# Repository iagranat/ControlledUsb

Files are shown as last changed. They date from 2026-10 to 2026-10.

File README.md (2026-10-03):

# Controlled USB 2.0 Extension Cable

An intelligent USB 2.0 High-Speed (480 Mbps) inline extension cable with host-controlled power & data disconnection.

---

## 🛠️ System Architecture

```
                  +-------------------------------------------------------------+
                  |                     USB DONGLE                              |
                  |                                                             |
USB-A Male ------>| ===> CH334F 2-Port USB Hub                                  |
(From PC)         |       |                                                     |
                  |       +-- Port 1 ----> Waveshare RP2040-Zero (USB CDC Serial|
                  |       |                (GP16 = Onboard WS2812 RGB LED)      |
                  |       |                         |                           |
                  |       |             GP14 (PWR)  | GP15 (DATA)               |
                  |       |             Active HIGH | Active LOW                |
                  |       |                         v                           |
                  |       +-- Port 2 --+-> [CH440G High-Speed Switch] (D+/D-) ->|---> USB-A Female
                  |                    |                                        |     (Target Device)
                  |                    +-> [TPS22918 Load Switch] (VBUS, 2A) -->|
                  |                                                             |
                  |   GND (Common ground throughout) -------------------------->|
                  +-------------------------------------------------------------+
```

---

## 📌 Pinout & Connections

### RP2040-Zero
| RP2040 Pin | Connected To | Description / Logic |
| :--- | :--- | :--- |
| **GP16** | *Onboard WS2812* | Status RGB LED (Green = ON, Red = OFF, Yellow = Cycling, Blue = Charge) |
| **GP14** | **TPS22918** `ON` | High-side power switch enable (Active **HIGH**: `1` = 5V ON, `0` = 0V OFF) |
| **GP15** | **CH440G** `EN` | USB data switch output enable (Active **LOW**: `0` = Pass, `1` = Cut) |
| **GP26** | **Push Button** | Tactile button to GND (Internal pull-up enabled) |

---

## 🚦 RGB Status Indications

| Color | State | $V_{BUS}$ (Power) | $D+/D-$ (Data) | Description |
| :--- | :---: | :---: | :---: | :--- |
| 🟢 **Green** | `CONNECTED` | **ON** | **ON** | Normal operation. |
| 🔴 **Red** | `DISCONNECTED`| **OFF** | **OFF** | Completely unpowered and un-enumerated. |
| 🔵 **Blue** | `CHARGE_ONLY` | **ON** | **OFF** | Safe charging without data communication. |
| 🟡 **Yellow** *(Blinking)* | `CYCLING` | *Rebooting* | *Rebooting* | Active reboot/cycle in progress. |

---

## 🕹️ Controls

### 1. Serial Commands (115200 baud, Newline)
* `ON` or `CONNECT` — Connect power and data (with safe sequencing).
* `OFF` or `DISCONNECT` — Disconnect data first, then cut power.
* `CHARGE` — Keep 5V active, cut data lines.
* `CYCLE <ms>` — Reboot port for specified milliseconds (e.g. `CYCLE 1500`).
* `STATUS` or `?` — Query current state.
* `HELP` — List commands.

### 2. Physical Button
* **Short Click (< 1.2s)**: Toggle between `CONNECTED` and `DISCONNECTED`.
* **Long Press (> 1.2s)**: Trigger automated 1-second power cycle (`CYCLE 1000`).

---

## 🚀 Building & Flashing with PlatformIO

1. Plug the **RP2040-Zero** into your PC while holding the **`BOOT`** button.
2. Open this folder in Antigravity IDE (with the PlatformIO extension installed).
3. Click the **Build** (`✓`) button in the bottom status bar.
4. Click the **Upload** (`→`) button to flash the firmware.
5. Click the **Serial Monitor** (`🔌`) button to open the terminal.

---

## 🐍 Python CLI Utility

Run from the `tools/` folder:
```powershell
python switch_cli.py on
python switch_cli.py off
python switch_cli.py cycle 1000
python switch_cli.py status
```

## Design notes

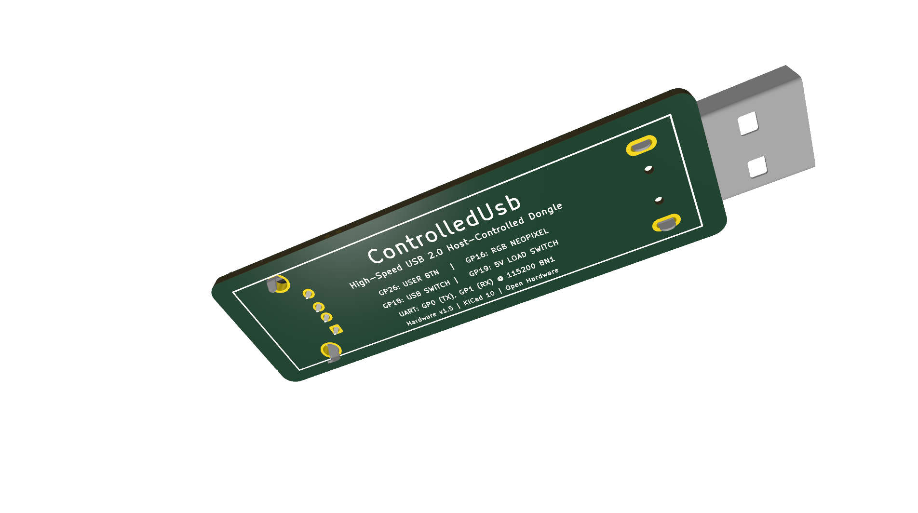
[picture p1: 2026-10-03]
hardware/ControlledUsb_3D_back.png

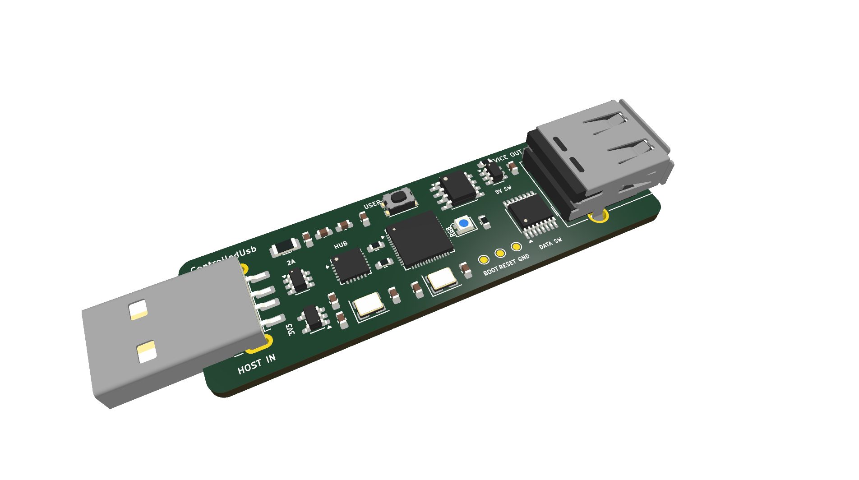
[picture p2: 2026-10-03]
hardware/ControlledUsb_3D_render.png

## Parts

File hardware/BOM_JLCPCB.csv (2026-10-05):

Comment | Designator | Footprint | LCSC Part #
RP2040 (Dual-Core Cortex-M0+ MCU) | U1 | Package_DFN_QFN:QFN-56-1EP_7x7mm_P0.4mm_EP3.2x3.2mm | C2040
PY25Q32HB-SSH-IR (4MB SPI Flash SOP-8) | U2 | Package_SO:SOIC-8_3.9x4.9mm_P1.27mm | C22439001
CH334F (USB 2.0 High-Speed 4-Port Hub QFN-24) | U3 | Package_DFN_QFN:QFN-24-1EP_4x4mm_P0.5mm_EP2.6x2.6mm | C5187527
TPS22918DBVR (5V 2A Load Switch SOT-23-6) | U4 | Package_TO_SOT_SMD:SOT-23-6 | C131941
CH440R (High-Speed USB Switch TSSOP-16) | U5 | Package_SO:TSSOP-16_4.4x5mm_P0.65mm | C282323
ME6211C33M5G-N (3.3V 500mA LDO SOT-23-5) | U6 | Package_TO_SOT_SMD:SOT-23-5 | C82942
USBLC6-2SC6 (USB ESD Protection SOT-23-6) | U7 | Package_TO_SOT_SMD:SOT-23-6 | C7519
12.000MHz SMD Crystal 3225-4P | Y1, Y2 | Crystal:Crystal_SMD_3225-4Pin_3.2x2.5mm | C9002
nSMD200 (PTC Resettable Fuse 2A 1206) | F1 | Fuse:Fuse_1206_3216Metric | C70085
USB-A Female Receptacle RA TH | J2 | Connector_USB:USB_A_Molex_67643_Horizontal | C2344
27R 1% 0603 | R1, R2 | Resistor_SMD:R_0603_1608Metric | C25114
10k 1% 0603 | R5, R6 | Resistor_SMD:R_0603_1608Metric | C25804
15pF 50V C0G 0603 | C1, C2 | Capacitor_SMD:C_0603_1608Metric | C1644
100nF 50V X7R 0603 | C3, C4, C5 | Capacitor_SMD:C_0603_1608Metric | C14663
1uF 50V X7R 0603 | C11 | Capacitor_SMD:C_0603_1608Metric | C15849
10uF 16V X5R 0603 | C13, C14, C15, C17 | Capacitor_SMD:C_0603_1608Metric | C19702

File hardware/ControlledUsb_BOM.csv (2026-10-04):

Refs | Value | Footprint | Qty | DNP
C1,C2 | 15pF | Capacitor_SMD:C_0603_1608Metric | 2
C3-C5 | 100nF | Capacitor_SMD:C_0603_1608Metric | 3
C11 | 1uF | Capacitor_SMD:C_0603_1608Metric | 1
C13-C15,C17 | 10uF | Capacitor_SMD:C_0603_1608Metric | 4
D1 | WS2812B | LED_SMD:LED_WS2812B-2020_PLCC4_2.0x2.0mm | 1
F1 | PTC 2A | Fuse:Fuse_1206_3216Metric | 1
J1 | USB_A_Male | Connector_USB:USB_A_CNCTech_1001-011-01101_Horizontal | 1
J2 | USB_A_Female | Connector_USB:USB_A_Molex_67643_Horizontal | 1
R1,R2 | 27R | Resistor_SMD:R_0603_1608Metric | 2
R5,R6 | 10k | Resistor_SMD:R_0603_1608Metric | 2
SW1 | USER_BTN | Button_Switch_SMD:SW_Push_1P1T_NO_CK_KMR2 | 1
TP1 | BOOT | TestPoint:TestPoint_Pad_D1.0mm | 1
TP2 | RESET | TestPoint:TestPoint_Pad_D1.0mm | 1
TP3 | GND | TestPoint:TestPoint_Pad_D1.0mm | 1
U1 | RP2040 | Package_DFN_QFN:QFN-56-1EP_7x7mm_P0.4mm_EP3.2x3.2mm | 1
U2 | W25Q32 | Package_SO:SOIC-8_3.9x4.9mm_P1.27mm | 1
U3 | CH334F | Package_DFN_QFN:QFN-24-1EP_4x4mm_P0.5mm_EP2.6x2.6mm | 1
U4 | TPS22918 | Package_TO_SOT_SMD:SOT-23-6 | 1
U5 | CH440P | Package_SO:TSSOP-16_4.4x5mm_P0.65mm | 1
U6 | ME6211C33 | Package_TO_SOT_SMD:SOT-23-5 | 1
U7 | USBLC6-2SC6 | Package_TO_SOT_SMD:SOT-23-6 | 1
Y1,Y2 | 12.000MHz | Crystal:Crystal_SMD_3225-4Pin_3.2x2.5mm | 2

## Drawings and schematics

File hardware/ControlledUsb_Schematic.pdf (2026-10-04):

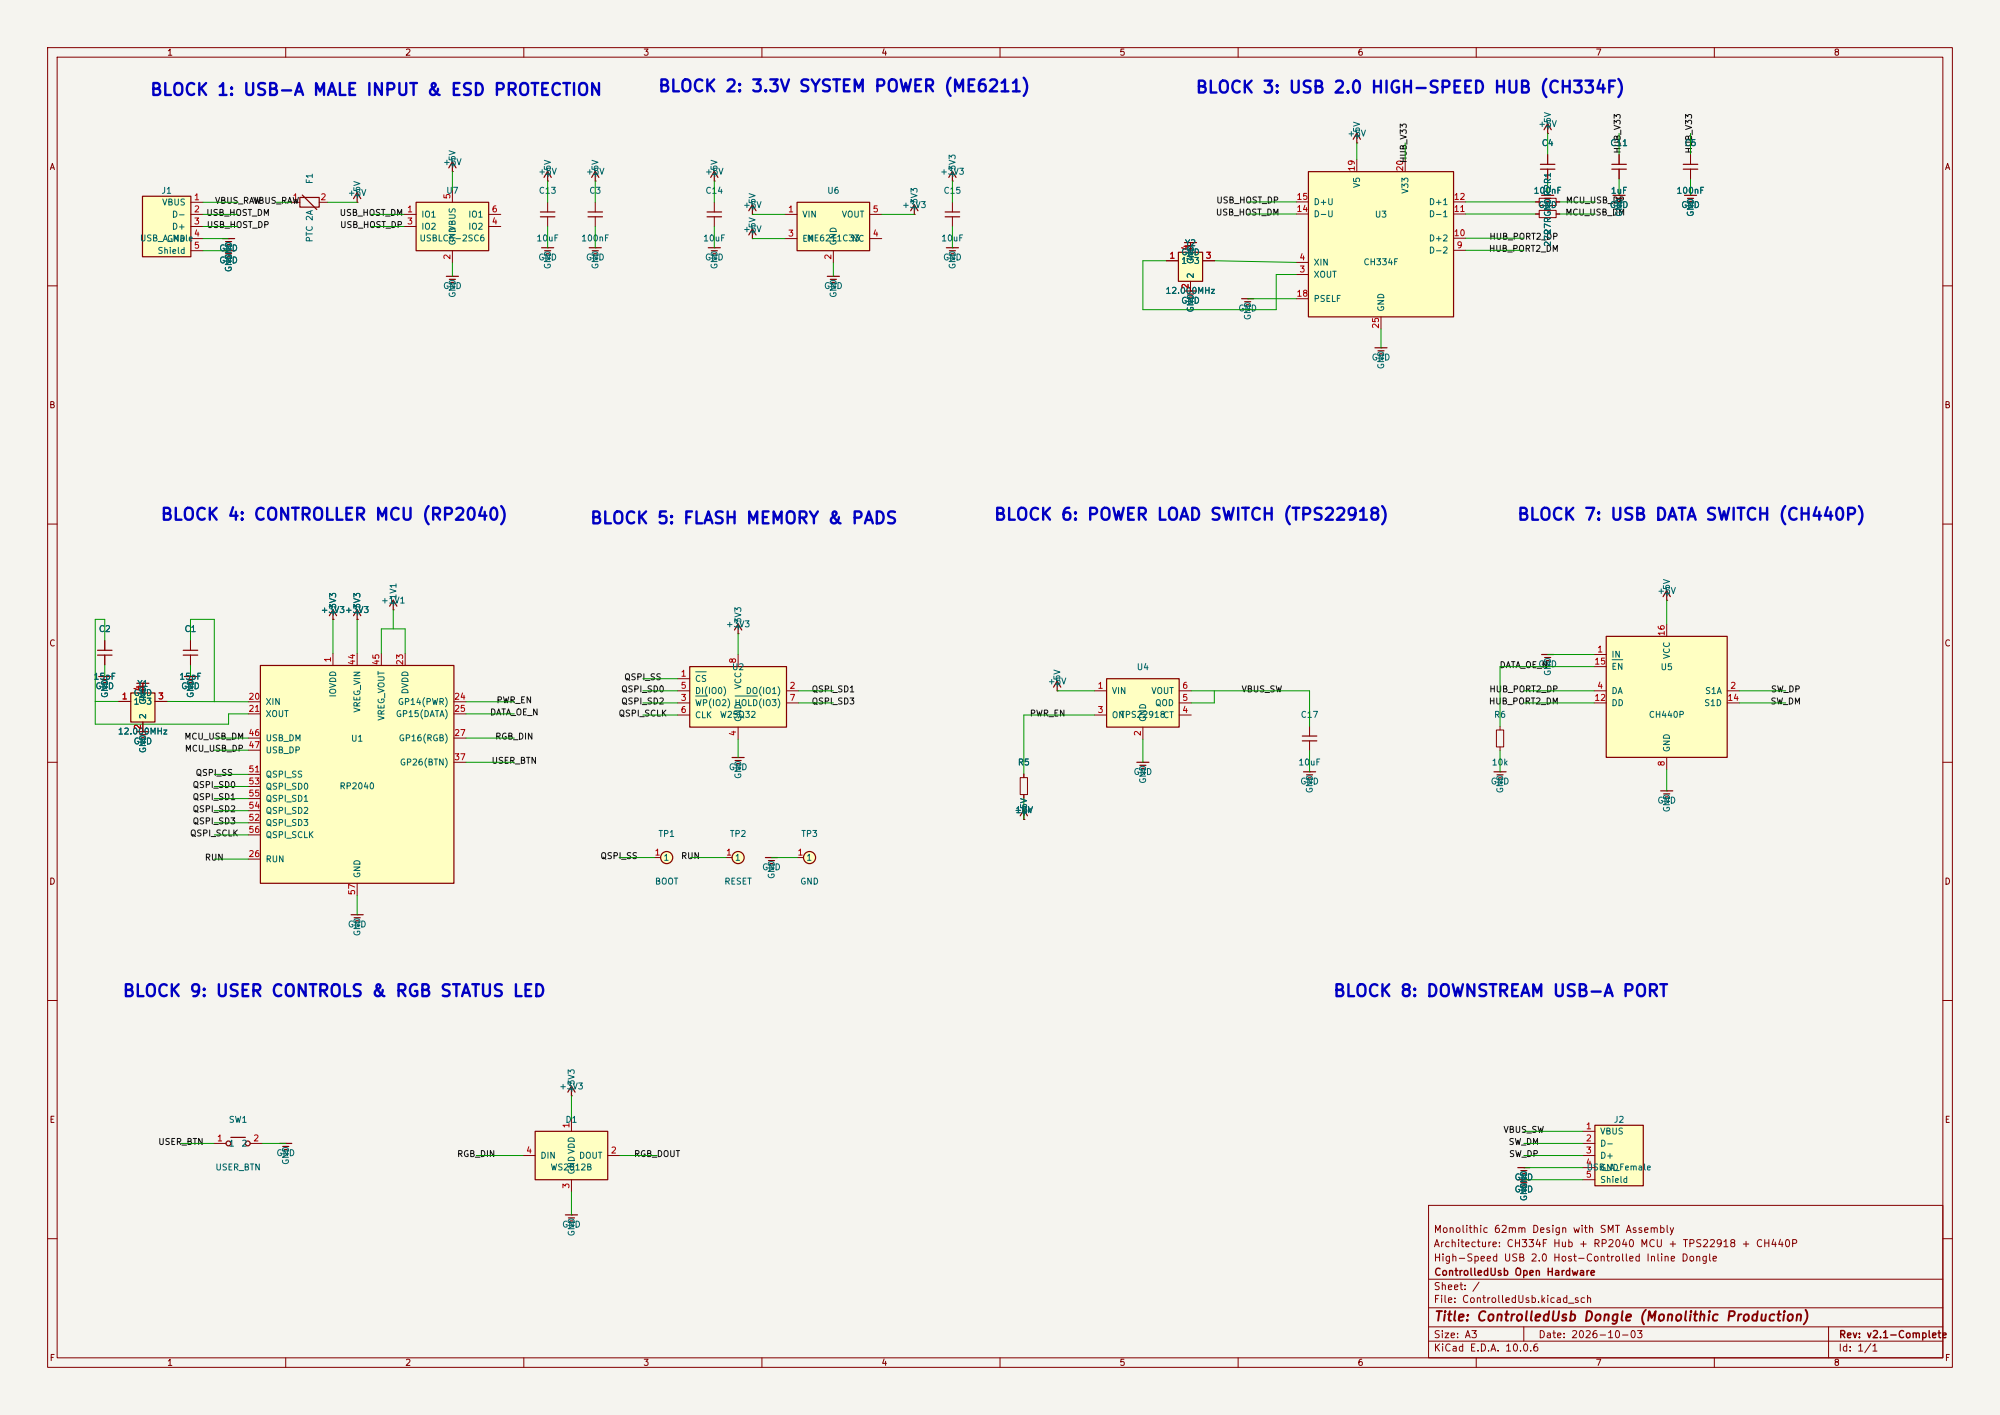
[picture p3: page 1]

BLOCK 1: USB-A MALE INPUT & ESD PROTECTION

BLOCK 3: USB 2.0 HIGH-SPEED HUB (CH334F)

USB_HOST_DM BLOCK 9: USER CONTROLS & RGB STATUS LED

Monolithic 62mm Design with SMT Assembly GND

8 U2 W25Q32 GND GND GND GND

BLOCK 5: FLASH MEMORY & PADS

BLOCK 7: USB DATA SWITCH (CH440P)

4 DI(IO0) 5 CLK 6 HOLD(IO3) 7 VCC

BLOCK 8: DOWNSTREAM USB-A PORT

Architecture: CH334F Hub + RP2040 MCU + TPS22918 + CH440P
High-Speed USB 2.0 Host-Controlled Inline Dongle
ControlledUsb Open Hardware
Sheet: /
File: ControlledUsb.kicad_sch
Title: ControlledUsb Dongle (Monolithic Production)

F Date: 2026-10-03

KiCad E.D.A. 10.0.6 | Id: 1/1

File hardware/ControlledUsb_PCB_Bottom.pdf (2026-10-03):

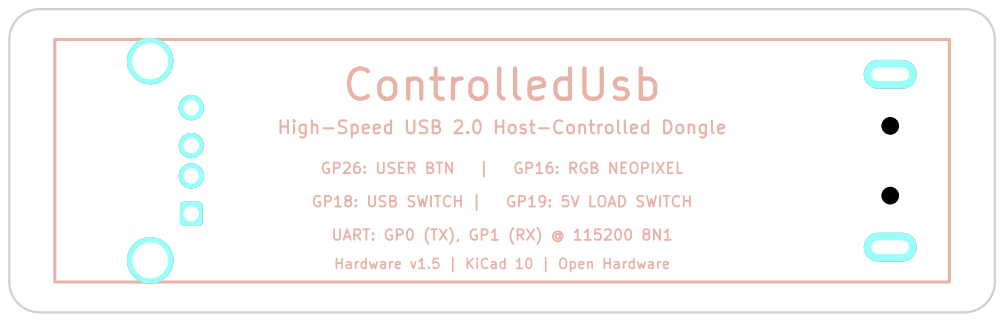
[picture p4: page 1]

UART: GP0 (TX), GP1 (RX) @ 115200 8N1 High-Speed USB 2.0 Host-Controlled Dongle ControlledUsb

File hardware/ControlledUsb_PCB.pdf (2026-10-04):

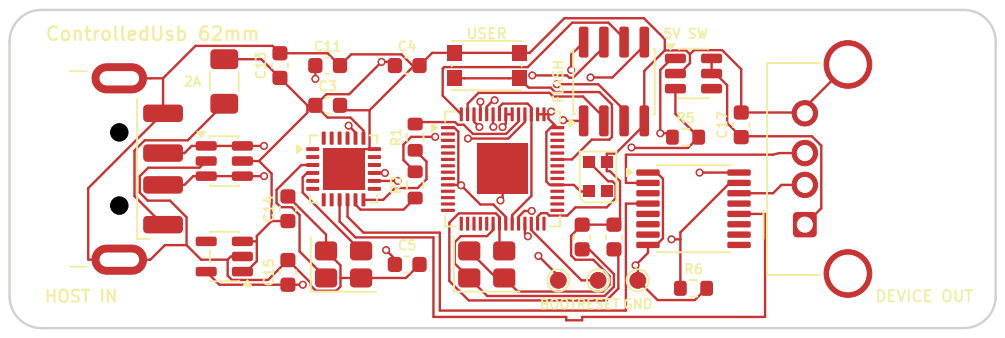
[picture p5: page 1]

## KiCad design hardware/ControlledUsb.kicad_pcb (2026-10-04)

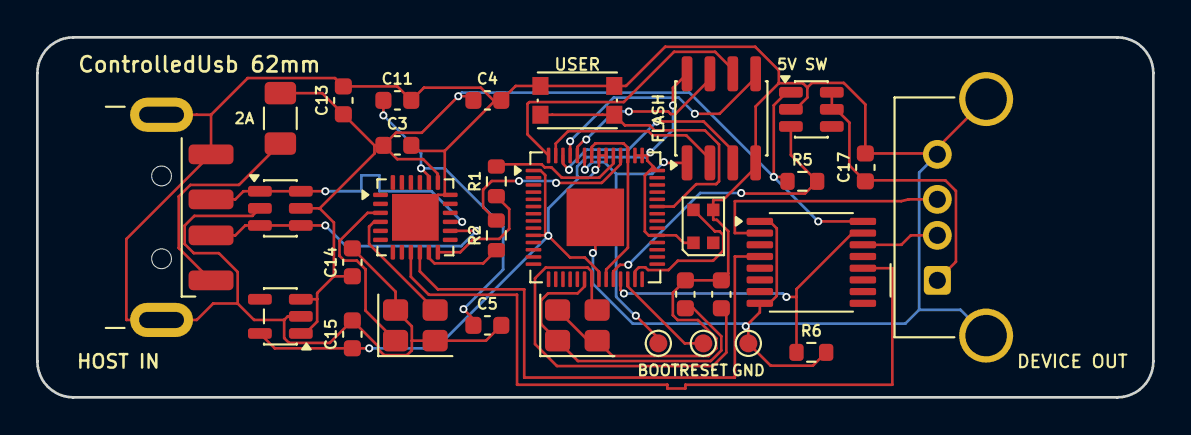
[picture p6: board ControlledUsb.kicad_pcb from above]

Board: 4 copper layers, 62.0 x 20.0 mm, 31 parts (0 on the bottom side), 32 nets.

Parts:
C1, C2: 15pF; C_0603_1608Metric
C3, C4, C5: 100nF; C_0603_1608Metric
C11: 1uF; C_0603_1608Metric
C13, C14, C15, C17: 10uF; C_0603_1608Metric
D1: WS2812B; LED_WS2812B-2020_PLCC4_2.0x2.0mm
F1: PTC 2A; Fuse_1206_3216Metric
J1: USB_A_Male; USB_A_CNCTech_1001-011-01101_Horizontal
J2: USB_A_Female; USB_A_Molex_67643_Horizontal
R1, R2: 27R; R_0603_1608Metric
R5, R6: 10k; R_0603_1608Metric
SW1: USER_BTN; SW_Push_1P1T_NO_CK_KMR2
TP1: BOOT; TestPoint_Pad_D1.0mm
TP2: RESET; TestPoint_Pad_D1.0mm
TP3: GND; TestPoint_Pad_D1.0mm
U1: RP2040; QFN-56-1EP_7x7mm_P0.4mm_EP3.2x3.2mm
U2: W25Q32; SOIC-8_3.9x4.9mm_P1.27mm
U3: CH334F; QFN-24-1EP_4x4mm_P0.5mm_EP2.6x2.6mm
U4: TPS22918; SOT-23-6
U5: CH440P; TSSOP-16_4.4x5mm_P0.65mm
U6: ME6211C33; SOT-23-5
U7: USBLC6-2SC6; SOT-23-6
Y1, Y2: 12.000MHz; Crystal_SMD_3225-4Pin_3.2x2.5mm

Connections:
+1V1: U1.23, U1.45, U1.50
+3V3: C15.1, D1.1, U1.1, U1.10, U1.22, U1.33, U1.42, U1.43, U1.44, U1.48, U1.49, U2.8, U6.5
+5V: F1.1, J1.1
+5V_FUSED: C3.1, C4.1, C13.1, C14.1, F1.2, R5.1, U3.19, U4.1, U5.16, U6.1, U6.3, U7.5
DATA_OE_N: R6.1, U1.25, U5.15
GND: C1.2, C2.2, C3.2, C4.2, C5.2, C11.2, C13.2, C14.2, C15.2, C17.2, D1.3, J1.4, J1.SH, J2.4, J2.SH, R6.2, SW1.1, TP3.1, U1.57, U2.4, U3.18, U3.25, U4.2, U5.1, U5.8, U6.2, U7.2, Y1.2, Y1.4, Y2.2, Y2.4
HUB_PORT1_DM: R2.1, U3.11
HUB_PORT1_DP: R1.1, U3.12
HUB_PORT2_DM: U3.9, U5.12
HUB_PORT2_DP: U3.10, U5.4
HUB_V33: C5.1, C11.1, U3.20
HUB_XI: U3.3, Y2.1
HUB_XO: U3.4, Y2.3
MCU_USB_DM: R2.2, U1.46
MCU_USB_DP: R1.2, U1.47
MCU_XI: C1.1, U1.20, Y1.1
MCU_XO: C2.1, U1.21, Y1.3
PWR_EN: R5.2, U1.24, U4.3
QSPI_SCLK: U1.56, U2.6
QSPI_SD0: U1.53, U2.5
QSPI_SD1: U1.55, U2.2
QSPI_SD2: U1.54, U2.3
QSPI_SD3: U1.52, U2.7
QSPI_SS: TP1.1, U1.51, U2.1
RGB_DIN: D1.4, U1.27
RUN: TP2.1, U1.26
SW_DM: J2.2, U5.14
SW_DP: J2.3, U5.2
USB_HOST_DM: J1.2, U3.14, U7.3, U7.4
USB_HOST_DP: J1.3, U3.15, U7.1, U7.6
USER_BTN: SW1.2, U1.37
VBUS_SW: C17.1, J2.1, U4.5, U4.6

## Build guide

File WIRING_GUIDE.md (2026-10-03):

# 🔌 Breadboard Wiring & Assembly Guide (Verified Working)

This guide details the exact, lab-verified breadboard wiring connections for **USBiagra** / **The Ilan-terrupter**.

---

## 📦 Components Overview

1. **CH334F 2-Port USB 2.0 Hub Breakout**
   * Upstream USB-C connects to PC Host.
   * `PORT1` (Top): Connects to RP2040-Zero (USB CDC Serial Controller).
   * `PORT2` (Bottom): Connects to Switched Downstream Port via TPS22918 & CH440G.
2. **Waveshare RP2040-Zero**
   * Firmware running Arduino/PlatformIO with USB CDC CLI, debounced button state machine, and NeoPixel status.
3. **CH440G USB 2.0 High-Speed Switch (SOP-16 Adapter)**
   * Switches differential data pair ($D+$ on Channel A, $D-$ on Channel D).
4. **TPS22918 Power Load Switch (SOT-23-6 DBV Adapter)**
   * Switches 5V $V_{BUS}$ up to 2A with Quick Output Discharge (QOD).
5. **USB-A Female Breakout**
   * Target downstream port.
6. **Push Button**
   * Connected between `GP26` and `GND`.

---

## 🗺️ Pin-to-Pin Connection Table

### 1. Power & Ground Rails
* **Hub `5V`** $\rightarrow$ **Breadboard Red (+) Rail**
* **Hub `GND`** $\rightarrow$ **Breadboard Blue (-) Rail**
* **All Grounds** (Hub, RP2040-Zero, CH440G Pin 8, TPS22918 Pin 2, USB-A Female GND) must tie to this common ground rail.

---

### 2. Hub Port 1 $\rightarrow$ RP2040-Zero (USB Serial CLI Control)
Using a 4-wire USB-C cable (plugged into RP2040-Zero USB-C receptacle) or direct wire:
* 🔴 **Red (5V)** $\rightarrow$ Hub Port 1 `5V` (or Breadboard 5V rail)
* ⚫ **Black (GND)** $\rightarrow$ Hub Port 1 `GND` (or Breadboard GND rail)
* 🟢 **Green (D+)** $\rightarrow$ Hub Port 1 `D+`
* ⚪ **White (D-)** $\rightarrow$ Hub Port 1 `D-`

---

### 3. CH440G Data Switch (SOP-16 Adapter) — *Verified Channels*
The CH440G switches the USB $D+/D-$ differential pair using Channel A and Channel D:

| CH440G Pin | Function | Connect To | Notes |
| :---: | :--- | :--- | :--- |
| **Pin 1** | `IN` | **GND Rail** | Selects Channel S1 (Low = S1 active) |
| **Pin 2** | `S1A` ($D+$ out) | **USB-A Female `D+`** | Switched $D+$ output to downstream port |
| **Pin 4** | `DA` ($D+$ in) | **Hub Port 2 `D+`** | High-speed $D+$ input from Hub |
| **Pin 8** | `GND` | **GND Rail** | System ground |
| **Pin 12** | `DD` ($D-$ in) | **Hub Port 2 `D-`** | High-speed $D-$ input from Hub |
| **Pin 14** | `S1D` ($D-$ out) | **USB-A Female `D-`** | Switched $D-$ output to downstream port |
| **Pin 15** | `EN#` | **RP2040 `GP15`** | Active LOW enable (0 = Pass, 1 = Tri-state). Add 10k pull-down to GND. |
| **Pin 16** | `VCC` | **5V Rail** | Chip power (place 0.1µF ceramic cap between Pin 16 and GND) |

*(Pins 3, 5, 6, 7, 9, 10, 11, 13 are unused/isolated).*

---

### 4. TPS22918 Power Switch (SOT-23-6 DBV Adapter) — *Verified Pinout*
Controls 5V $V_{BUS}$ power line up to 2A with active discharge:

| TPS22918 Pin | Function | Connect To | Notes |
| :---: | :--- | :--- | :--- |
| **Pin 1** | `VIN` | **Breadboard 5V Rail** | 5V Input from Hub. Add 1µF–10µF bulk capacitor to GND. |
| **Pin 2** | `GND` | **GND Rail** | System ground |
| **Pin 3** | `ON` | **RP2040 `GP14`** | Active HIGH enable (1 = 5V ON, 0 = 0V OFF). Add 10k pull-up to 5V. |
| **Pin 4** | `CT` | *Leave Floating* | Slew rate capacitor (internal fast ~100µs ramp) |
| **Pin 5** | `QOD` | **Tie to Pin 6 (`VOUT`)** | Quick Output Discharge (bleeds downstream rail to 0V when OFF) |
| **Pin 6** | `VOUT` | **USB-A Female `VBUS`** | Switched 5V output to downstream port |

---

### 5. Downstream Extension Port (USB-A Female Breakout)
* **`VBUS`** $\rightarrow$ From TPS22918 **Pin 6 (`VOUT`)**
* **`D-`** $\rightarrow$ From CH440G **Pin 14 (`S1D`)**
* **`D+`** $\rightarrow$ From CH440G **Pin 2 (`S1A`)**
* **`GND`** $\rightarrow$ Common **GND Rail**

---

### 6. Physical Controls & RP2040 Pin Assignment
* **`GP14`** $\rightarrow$ TPS22918 Pin 3 (`ON`)
* **`GP15`** $\rightarrow$ CH440G Pin 15 (`EN#`)
* **`GP26`** $\rightarrow$ Push button (other terminal to `GND`)
* **`GP16`** $\rightarrow$ Onboard WS2812 RGB LED:
  * 🟢 **Solid Green**: Connected (Power ON, Data ON)
  * 🔴 **Solid Red**: Disconnected (Power OFF, Data OFF)
  * 🔵 **Solid Blue**: Charge Only (Power ON, Data OFF)
  * 🟡 **Blinking Yellow**: Power Cycling (Auto reboot)

---

## ⚡ High-Speed (480 Mbps) Wiring Guidelines

When testing high-speed devices (flash drives, SSDs, webcams) on breadboard:
1. **Short Length**: Keep $D+$ and $D-$ wire runs as short as possible (~3 to 5 cm max).
2. **Length Match**: Cut the $D+$ and $D-$ wires to the identical length (within 2-3 mm).
3. **Twisted Pairs**: Lightly twist the Hub $D+/D-$ pair together, and the USB-A Female $D+/D-$ pair together to preserve 90Ω differential impedance.
4. **Direct Ground Return**: Ensure the USB-A Female GND wire runs directly to the common ground rail adjacent to the signal wires.

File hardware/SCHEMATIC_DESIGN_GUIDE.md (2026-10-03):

# 📐 ControlledUsb Hardware Design & Schematic Guide

**Version**: 1.0 (Monolithic Production Architecture)  
**Form Factor**: Slim USB Dongle (approx. 19 mm × 54 mm)  
**Target Fabrication**: JLCPCB 4-Layer PCB with SMT Assembly (Target total order < $55 USD)

---

## 1. System Architecture Overview

```mermaid
flowchart LR
    Host["Host PC<br/>(USB-A Male)"] --> FUSE["PTC 2A Fuse<br/>& USBLC6 ESD"]
    FUSE --> VBUS_BUS["+5V Main Rail"]
    FUSE --> HUB["WCH CH334F<br/>USB 2.0 Hub (QFN-24)"]
    
    VBUS_BUS --> LDO["ME6211<br/>3.3V LDO"]
    LDO --> RP["RP2040 MCU<br/>& W25Q32 Flash"]
    
    HUB -- "Port 1 (Full-Speed)" --> RP
    
    RP -- "GP14 (PWR_EN)" --> TPS["TI TPS22918<br/>Power Switch"]
    RP -- "GP15 (DATA_OE#)" --> CH440["WCH CH440P<br/>High-Speed Switch"]
    RP -- "GP16 (RGB)" --> LED["WS2812B-2020<br/>Status NeoPixel"]
    RP -- "GP26 (BTN)" --> BTN["User Tactile<br/>Push Button"]
    
    VBUS_BUS --> TPS
    HUB -- "Port 2 (High-Speed)" --> CH440
    
    TPS -- "VBUS_SW (Switched 5V)" --> OUT["USB-A Female<br/>Downstream Port"]
    CH440 -- "D+/D- (Switched Data)" --> OUT
```

---

## 2. Detailed Circuit Subsystems & Pin Connections

### Block 1: Upstream USB Input & Protection
* **Connector `J1`**: USB-A Male Plug (SMD + Through-hole retention tabs, LCSC `C77873`).
* **Overcurrent Protection `F1`**: 2.0A Hold / 4.0A Trip Resettable PTC Fuse (1206, LCSC `C394336`) in series with `VBUS`.
  * `VBUS_RAW` $\rightarrow$ `F1` $\rightarrow$ `+5V` Net.
* **ESD Protection `U7`**: USBLC6-2SC6 (SOT-23-6, LCSC `C7519`):
  * Pin 1 (`I/O1`): Upstream $D-$
  * Pin 2 (`GND`): System Ground
  * Pin 3 (`I/O2`): Upstream $D+$
  * Pin 4 (`I/O2`): Tied to Pin 3
  * Pin 5 (`VBUS`): Connected to `+5V`
  * Pin 6 (`I/O1`): Tied to Pin 1
* **Input Bulk Decoupling**: $10\mu\text{F}$ 16V ceramic (`C13`) + $100\text{nF}$ ceramic (`C3`).

---

### Block 2: 3.3V Power Supply (LDO)
* **Regulator `U6`**: MicrOne ME6211C33M5G-N (SOT-23-5, LCSC `C82942`):
  * Pin 1 (`VIN`): Connected to `+5V`
  * Pin 2 (`GND`): Ground
  * Pin 3 (`EN`): Connected to `+5V`
  * Pin 4 (`NC/BYP`): Open
  * Pin 5 (`VOUT`): `+3V3` Net (supplies RP2040 and Flash).
* **Decoupling**: $10\mu\text{F}$ 16V ceramic on input (`C14`) and output (`C15`).

---

### Block 3: USB 2.0 Hub Controller (WCH CH334F)
* **IC `U3`**: WCH CH334F (QFN-24, 4×4 mm, LCSC `C5142940`):
  * **Pin 19 (`V5`)**: Connects to `+5V` (with $10\mu\text{F}$ `C16` + $100\text{nF}$ `C4` to GND).
  * **Pin 20 (`V33`)**: Internal 3.3V LDO output. Decouple with $1\mu\text{F}$ `C11` + $100\text{nF}$ `C5` to GND.
  * **Pin 25 (Exposed Pad / EPAD)**: Direct connection to solid Ground plane.
  * **Pins 3 (`XOUT`) & 4 (`XIN`)**: 12.000 MHz SMD Crystal (`Y2`, 3225 package, LCSC `C16212`).
  * **Upstream Port**:
    * Pin 15 (`D+U`): Connects to Host $D+$
    * Pin 14 (`D-U`): Connects to Host $D-$
  * **Port 1 (Internal Controller Link to RP2040)**:
    * Pin 12 (`D+1`): Connects to RP2040 `USB_DP` through $27\ \Omega$ series resistor (`R1`).
    * Pin 11 (`D-1`): Connects to RP2040 `USB_DM` through $27\ \Omega$ series resistor (`R2`).
  * **Port 2 (Switched Peripheral Link)**:
    * Pin 10 (`D+2`): Connects to CH440P Pin 4 (`DA`).
    * Pin 9 (`D-2`): Connects to CH440P Pin 12 (`DD`).
  * **Unused Pins**:
    * Pins 5, 6, 7, 8 (Ports 3 & 4 data lines): Leave Floating / NC.
    * Pin 1 (`!OVCUR`): Pull up to 3.3V or leave NC (internal pull-up).
    * Pin 16 (`!RESET`): Leave NC (internal power-on reset).
    * Pin 18 (`PSELF`): Connect to GND (Bus-powered mode).

---

### Block 4: Microcontroller Core (Raspberry Pi RP2040)
* **MCU `U1`**: Raspberry Pi RP2040 (QFN-56, 7×7 mm, LCSC `C2040`):
  * **Power Supply**:
    * `IOVDD` (Pins 1, 10, 22, 33, 42, 49) $\rightarrow$ `+3V3` Net (each with a $100\text{nF}$ cap `C6`, `C7`, `C8`, `C9`).
    * `DVDD` (Pins 23, 50) $\rightarrow$ `+1V1` Net (internal core voltage).
    * `VREG_VIN` (Pin 44) $\rightarrow$ `+3V3`.
    * `VREG_VOUT` (Pin 45) $\rightarrow$ `+1V1` Net, decoupled with $1\mu\text{F}$ `C12` + $100\text{nF}$ `C10`.
    * `USB_VDD` (Pin 48) $\rightarrow$ `+3V3`.
    * `ADC_AVDD` (Pin 43) $\rightarrow$ `+3V3`.
    * `GND` (Pin 57 EPAD) $\rightarrow$ Direct Ground plane.
  * **Clock**:
    * Pins 20 (`XIN`) & 21 (`XOUT`) $\rightarrow$ 12.000 MHz Crystal (`Y1`, LCSC `C16212`) with $15\text{pF}$ loading caps (`C1`, `C2`) to GND.
  * **USB 1.1 / 2.0 Interface**:
    * Pin 46 (`USB_DM`) $\rightarrow$ $27\ \Omega$ (`R2`) $\rightarrow$ CH334F Pin 11 (`D-1`).
    * Pin 47 (`USB_DP`) $\rightarrow$ $27\ \Omega$ (`R1`) $\rightarrow$ CH334F Pin 12 (`D+1`).
  * **SPI Flash Memory `U2`**: Winbond W25Q32JVSSIQ (SOIC-8, 4MB, LCSC `C7405788`):
    * `QSPI_SD0` (Pin 53) $\leftrightarrow$ Flash Pin 5 (`DI / IO0`)
    * `QSPI_SD1` (Pin 55) $\leftrightarrow$ Flash Pin 2 (`DO / IO1`)
    * `QSPI_SD2` (Pin 54) $\leftrightarrow$ Flash Pin 3 (`WP# / IO2`)
    * `QSPI_SD3` (Pin 52) $\leftrightarrow$ Flash Pin 7 (`HOLD# / IO3`)
    * `QSPI_SCLK` (Pin 56) $\leftrightarrow$ Flash Pin 6 (`CLK`)
    * `QSPI_SS` (Pin 51) $\leftrightarrow$ Flash Pin 1 (`CS#`)
  * **Buttons**:
    * **BOOT Button `SW2`**: Tactile switch to GND through $1\text{k}\ \Omega$ resistor (`R7`) to `QSPI_SS`.
    * **RESET Button `SW3`**: Tactile switch pulling `RUN` (Pin 26) to GND. (Add $10\text{k}\ \Omega$ pull-up `R8` to `+3V3`).
    * **USER Button `SW1`**: Tactile switch pulling `GP26` (Pin 37) to GND.
  * **Status NeoPixel `D1`**: WS2812B-2020 (LCSC `C2843785`):
    * `DIN` connects to RP2040 `GP16` (Pin 27).
    * `VDD` connects to `+5V` (or `+3V3`), `GND` to Ground.
  * **Control Outputs**:
    * `GP14` (Pin 24) $\rightarrow$ Power switch `ON` net.
    * `GP15` (Pin 25) $\rightarrow$ Data switch `EN#` net.

---

### Block 5: Power Load Switch (TI TPS22918)
* **IC `U4`**: Texas Instruments TPS22918DBVR (SOT-23-6 DBV, LCSC `C2835607`):
  * **Pin 1 (`VIN`)**: Connected to `+5V` bus.
  * **Pin 2 (`GND`)**: System Ground.
  * **Pin 3 (`ON`)**: Connected to RP2040 `GP14` + $10\text{k}\ \Omega$ pull-up (`R5`) to `+5V` (ensures default-ON).
  * **Pin 4 (`CT`)**: Left floating (fast ~100 µs rise time).
  * **Pin 5 (`QOD`)**: Tied directly to Pin 6 (`VOUT`) for active quick discharge to 0V when OFF.
  * **Pin 6 (`VOUT`)**: Output net `VBUS_SW` feeding downstream USB-A female.

---

### Block 6: High-Speed USB Analog Switch (WCH CH440P)
* **IC `U5`**: WCH CH440P (TSSOP-16, LCSC `C53407`):
  * **Pin 1 (`IN`)**: Tied to GND (permanently selects S1 channel).
  * **Pin 2 (`S1A`)**: Switched $D+$ out $\rightarrow$ Downstream USB-A Female $D+$.
  * **Pin 4 (`DA`)**: Hub Port 2 $D+$ in $\rightarrow$ CH334F Pin 10 (`D+2`).
  * **Pin 8 (`GND`)**: System Ground.
  * **Pin 12 (`DD`)**: Hub Port 2 $D-$ in $\rightarrow$ CH334F Pin 9 (`D-2`).
  * **Pin 14 (`S1D`)**: Switched $D-$ out $\rightarrow$ Downstream USB-A Female $D-$.
  * **Pin 15 (`EN#`)**: Active LOW enable $\rightarrow$ Connected to RP2040 `GP15` + $10\text{k}\ \Omega$ pull-down (`R6`) to GND (default-ON).
  * **Pin 16 (`VCC`)**: Connected to `+5V` bus + $100\text{nF}$ decoupling cap to GND.
  * *(Pins 3, 5, 6, 7, 9, 10, 11, 13 are unused/NC).*

---

### Block 7: Downstream USB-A Female & Protection
* **Connector `J2`**: USB-A Female Receptacle (Horizontal Through-Hole tabs, LCSC `C10398`):
  * Pin 1 (`VBUS`): Connected to `VBUS_SW` (from TPS22918 `VOUT`).
  * Pin 2 (`D-`): Connected to CH440P Pin 14 (`S1D`).
  * Pin 3 (`D+`): Connected to CH440P Pin 2 (`S1A`).
  * Pin 4 (`GND`): Connected to System Ground.
  * Shield Tabs: Connected to System Ground.
* **ESD Protection `U8`**: USBLC6-2SC6 (SOT-23-6, LCSC `C7519`) across `VBUS_SW`, $D+$, $D-$, and `GND`.
* **Output Bulk Cap**: $10\mu\text{F}$ 16V ceramic (`C16`) on `VBUS_SW`.

---

## 3. High-Speed 4-Layer PCB Stackup & RF Routing

To ensure flawless **480 Mbps USB 2.0 High-Speed** operation:

### Layer Stackup: JLCPCB JLC04161H (1.6 mm thickness)
* **Layer 1 (Top)**: $90\ \Omega$ Differential Pairs ($D+/D-$) and component pads.
* **Layer 2 (In1)**: **Solid Unbroken Ground (GND) Plane**. (Acts as RF reference for Layer 1).
* **Layer 3 (In2)**: Power distribution (`+5V`, `+3V3`, `+1V1`).
* **Layer 4 (Bottom)**: Low-speed signals, user controls, and ground shield pour.

### $90\ \Omega$ Differential Microstrip Parameters (Layer 1 over Layer 2)
* **Trace Width ($W$)**: $0.15\text{ mm}$ (6 mil)
* **Differential Spacing ($S$)**: $0.15\text{ mm}$ (6 mil)
* **Dielectric Height to GND ($H$)**: $0.1\text{ mm}$ (Prepreg 7628 / 2116)
* **Trace Length Matching**: Skew between $D+$ and $D-$ within each pair must be $< 0.15\text{ mm}$ ($< 6\text{ mil}$).
* **Avoid Vias on USB Pairs**: Route the differential traces entirely on the Top layer without layer transitions.

---

## 4. JLCPCB Assembly & Budget Verification

| Expense Category | 5 Assembled Boards (USD) |
| :--- | :--- |
| **PCB Fabrication (4-Layer, Green/Black, 1.6mm)** | $2.00 |
| **SMT Setup Fee** | $8.00 |
| **SMT Stencil Fee** | $1.50 |
| **LCSC Components (All 5 boards)** | ~$20.00 |
| **Extended Part Loading Fees (~4 parts @ $3)** | ~$12.00 |
| **Shipping to Israel (Global Direct Line)** | ~$12.00 |
| **TOTAL ESTIMATED COST** | **~$55.50 USD** |

✅ **Customs Exemption**: Well under the **$75.00 USD** threshold for 0% VAT and duty-free import into Israel!

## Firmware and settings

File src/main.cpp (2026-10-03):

#include <Arduino.h>
#include <Adafruit_NeoPixel.h>

// ================= Pin Definitions =================
#define PIN_RGB_LED    16  // Onboard WS2812 on RP2040-Zero
#define PIN_PWR_EN     14  // TPS22918 Enable (Active HIGH: 1 = 5V ON, 0 = 0V OFF)
#define PIN_DATA_OE    15  // CH440G Enable   (Active LOW:  0 = Data ON, 1 = Hi-Z Cut)
#define PIN_BUTTON     26  // Tactile push button to GND (moved to GP26 on active row)

// NeoPixel Configuration (1 on-board pixel)
Adafruit_NeoPixel rgb(1, PIN_RGB_LED, NEO_GRB + NEO_KHZ800);

// ================= State Machine =================
enum PortState {
  STATE_CONNECTED,
  STATE_DISCONNECTED,
  STATE_CHARGE_ONLY,
  STATE_CYCLING
};

PortState currentState = STATE_CONNECTED;

// Timing & Blinking
unsigned long cycleStartTime = 0;
unsigned long cycleDurationMs = 1000;
unsigned long lastBlinkTime = 0;
bool blinkState = false;

// Button Debouncing & Long-Press Detection
int lastButtonReading = HIGH;
int buttonState = HIGH;
unsigned long lastDebounceTime = 0;
unsigned long buttonPressStartTime = 0;
const unsigned long debounceDelay = 50;
const unsigned long longPressThreshold = 1200; // 1.2s triggers power cycle

// ================= LED Color Helper =================

void setRgb(uint8_t r, uint8_t g, uint8_t b) {
  rgb.setPixelColor(0, rgb.Color(r, g, b));
  rgb.show();
}

void updateLedState() {
  switch (currentState) {
    case STATE_CONNECTED:
      setRgb(0, 45, 0);     // 🟢 Solid Green
      break;

    case STATE_DISCONNECTED:
      setRgb(45, 0, 0);     // 🔴 Solid Red
      break;

    case STATE_CHARGE_ONLY:
      setRgb(0, 0, 45);     // 🔵 Solid Blue
      break;

    case STATE_CYCLING:
      // 🟡 Blinking Yellow during reboot
      if (millis() - lastBlinkTime > 120) {
        lastBlinkTime = millis();
        blinkState = !blinkState;
        if (blinkState) {
          setRgb(45, 35, 0); // Yellow ON
        } else {
          setRgb(0, 0, 0);   // OFF
        }
      }
      break;
  }
}

// ================= Switching Logic =================

// Safe Reconnect: Turn on Power first, then connect Data lines
void connectPort() {
  digitalWrite(PIN_PWR_EN, HIGH); // 1. Turn on 5V VBUS
  delay(30);                      // 2. Wait 30ms for downstream caps to charge
  digitalWrite(PIN_DATA_OE, LOW); // 3. Connect D+/D- data lines (Active LOW)
  currentState = STATE_CONNECTED;
  updateLedState();
  Serial.println("OK: CONNECTED (VBUS=ON, DATA=ON)");
}

// Safe Disconnect: Cut Data lines first, then cut Power
void disconnectPort() {
  digitalWrite(PIN_DATA_OE, HIGH); // 1. Tri-state D+/D- first to prevent back-powering!
  delay(5);                        // 2. Micro-gap
  digitalWrite(PIN_PWR_EN, LOW);   // 3. Cut VBUS to 0V (TPS22918 quick discharge bleeds rail)
  currentState = STATE_DISCONNECTED;
  updateLedState();
  Serial.println("OK: DISCONNECTED (VBUS=OFF, DATA=OFF)");
}

// Charge Only: Power ON, Data lines cut
void chargeOnlyPort() {
  digitalWrite(PIN_DATA_OE, HIGH); // Cut data
  digitalWrite(PIN_PWR_EN, HIGH);  // Keep 5V active
  currentState = STATE_CHARGE_ONLY;
  updateLedState();
  Serial.println("OK: CHARGE_ONLY (VBUS=ON, DATA=OFF)");
}

// Automated Cycle (Reboot)
void startCycle(unsigned long durationMs) {
  cycleDurationMs = durationMs;
  cycleStartTime = millis();

  // Cut both lines safely
  digitalWrite(PIN_DATA_OE, HIGH);
  delay(5);
  digitalWrite(PIN_PWR_EN, LOW);

  currentState = STATE_CYCLING;
  updateLedState();
  Serial.printf("OK: CYCLING (Rebooting port for %lu ms)...\n", durationMs);
}

// ================= Serial CLI Parser =================

void processSerialCommand(String cmd) {
  cmd.trim();
  cmd.toUpperCase();

  if (cmd.length() == 0) return;

  if (cmd == "ON" || cmd == "CONNECT" || cmd == "1") {
    connectPort();
  } 
  else if (cmd == "OFF" || cmd == "DISCONNECT" || cmd == "0") {
    disconnectPort();
  } 
  else if (cmd == "CHARGE") {
    chargeOnlyPort();
  } 
  else if (cmd.startsWith("CYCLE")) {
    int spaceIndex = cmd.indexOf(' ');
    unsigned long duration = 1000;
    if (spaceIndex != -1) {
      long val = cmd.substring(spaceIndex + 1).toInt();
      if (val > 0) duration = (unsigned long)val;
    }
    startCycle(duration);
  } 
  else if (cmd == "STATUS" || cmd == "?") {
    Serial.print("STATUS: ");
    switch (currentState) {
      case STATE_CONNECTED:    Serial.println("CONNECTED [VBUS=1, DATA=1]"); break;
      case STATE_DISCONNECTED: Serial.println("DISCONNECTED [VBUS=0, DATA=0]"); break;
      case STATE_CHARGE_ONLY:  Serial.println("CHARGE_ONLY [VBUS=1, DATA=0]"); break;
      case STATE_CYCLING:      Serial.printf("CYCLING [Remaining: %lu ms]\n", 
                                  (millis() - cycleStartTime < cycleDurationMs) ? 
                                  (cycleDurationMs - (millis() - cycleStartTime)) : 0); break;
    }
  } 
  else if (cmd == "HELP") {
    Serial.println("==========================================");
    Serial.println("  Controlled USB Extension Commands:");
    Serial.println("    ON / CONNECT     - Enable Power & Data");
    Serial.println("    OFF / DISCONNECT - Cut Power & Data");
    Serial.println("    CHARGE           - Power ON, Data OFF");
    Serial.println("    CYCLE <ms>       - Power cycle (e.g. CYCLE 1000)");
    Serial.println("    STATUS / ?       - Query current state");
    Serial.println("==========================================");
  } 
  else {
    Serial.printf("ERR: Unknown command '%s'. Type HELP for command list.\n", cmd.c_str());
  }
}

// ================= Button Handler =================

void handleButton() {
  int reading = digitalRead(PIN_BUTTON);

  if (reading != lastButtonReading) {
    lastDebounceTime = millis();
  }

  if ((millis() - lastDebounceTime) > debounceDelay) {
    if (reading != buttonState) {
      buttonState = reading;

      // Button Pressed (LOW)
      if (buttonState == LOW) {
        buttonPressStartTime = millis();
      } 
      // Button Released (HIGH)
      else {
        unsigned long pressDuration = millis() - buttonPressStartTime;
        if (pressDuration >= longPressThreshold) {
          Serial.println("[Button] Long press -> Triggering 1s cycle");
          startCycle(1000);
        } else {
          // Short click -> Toggle between Connected and Disconnected
          if (currentState == STATE_CONNECTED) {
            Serial.println("[Button] Click -> Disconnecting");
            disconnectPort();
          } else {
            Serial.println("[Button] Click -> Connecting");
            connectPort();
          }
        }
      }
    }
  }
  lastButtonReading = reading;
}

// ================= Setup & Main Loop =================

void setup() {
  // Initialize Hardware Pins
  pinMode(PIN_PWR_EN, OUTPUT);
  pinMode(PIN_DATA_OE, OUTPUT);
  pinMode(PIN_BUTTON, INPUT_PULLUP);

  // Initialize Onboard WS2812 RGB LED
  rgb.begin();
  rgb.setBrightness(50); // Comfortable brightness

  // Default Boot State: CONNECTED
  connectPort();

  // Initialize Native USB CDC Serial
  Serial.begin(115200);

  // Wait up to 2 seconds for USB terminal to open
  unsigned long start = millis();
  while (!Serial && (millis() - start < 2000));

  Serial.println("\n==========================================");
  Serial.println("Controlled USB Extension Switch (RP2040)");
  Serial.println("Default State: CONNECTED");
  Serial.println("Type HELP for available commands.");
  Serial.println("==========================================");
}

void loop() {
  // 1. Process Serial CLI commands
  if (Serial.available() > 0) {
    String input = Serial.readStringUntil('\n');
    processSerialCommand(input);
  }

  // 2. Non-blocking cycle completion
  if (currentState == STATE_CYCLING) {
    if (millis() - cycleStartTime >= cycleDurationMs) {
      connectPort();
    }
  }

  // 3. Physical button checks
  handleButton();

  // 4. Update RGB LED animations
  updateLedState();
}

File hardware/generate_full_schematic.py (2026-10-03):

import subprocess
import uuid
import os

def uid():
    return str(uuid.uuid4())

def generate_schematic():
    root_uuid = "4c38a598-fbac-4a7d-94fb-08842dc4d130"
    
    # -------------------------------------------------------------
    # 1. Symbol Library Definitions
    # -------------------------------------------------------------
    lib_symbols = f"""	(lib_symbols
		(symbol "ControlledUsb:R_Small"
			(pin_numbers (hide yes))
			(pin_names (offset 0.254) (hide yes))
			(exclude_from_sim no) (in_bom yes) (on_board yes)
			(property "Reference" "R" (at 0 0 90) (effects (font (size 1.27 1.27))))
			(property "Value" "R_Small" (at 1.778 0 90) (effects (font (size 1.27 1.27))))
			(property "Footprint" "" (at 0 0 0) (effects (font (size 1.27 1.27)) (hide yes)))
			(property "Datasheet" "" (at 0 0 0) (effects (font (size 1.27 1.27)) (hide yes)))
			(property "Description" "" (at 0 0 0) (effects (font (size 1.27 1.27)) (hide yes)))
			(symbol "R_Small_0_1"
				(rectangle (start -0.762 1.778) (end 0.762 -1.778) (stroke (width 0.2032)) (fill (type none)))
			)
			(symbol "R_Small_1_1"
				(pin passive line (at 0 2.54 270) (length 0.762) (name "~" (effects (font (size 1.27 1.27)))) (number "1" (effects (font (size 1.27 1.27)))))
				(pin passive line (at 0 -2.54 90) (length 0.762) (name "~" (effects (font (size 1.27 1.27)))) (number "2" (effects (font (size 1.27 1.27)))))
			)
		)
		(symbol "ControlledUsb:C_Small"
			(pin_numbers (hide yes))
			(pin_names (offset 0.254) (hide yes))
			(exclude_from_sim no) (in_bom yes) (on_board yes)
			(property "Reference" "C" (at 0.635 2.54 0) (effects (font (size 1.27 1.27)) (justify left)))
			(property "Value" "C_Small" (at 0.635 -2.54 0) (effects (font (size 1.27 1.27)) (justify left)))
			(property "Footprint" "" (at 0 0 0) (effects (font (size 1.27 1.27)) (hide yes)))
			(property "Datasheet" "" (at 0 0 0) (effects (font (size 1.27 1.27)) (hide yes)))
			(property "Description" "" (at 0 0 0) (effects (font (size 1.27 1.27)) (hide yes)))
			(symbol "C_Small_0_1"
				(polyline (pts (xy -1.524 0.508) (xy 1.524 0.508)) (stroke (width 0.254)))
				(polyline (pts (xy -1.524 -0.508) (xy 1.524 -0.508)) (stroke (width 0.254)))
			)
			(symbol "C_Small_1_1"
				(pin passive line (at 0 2.54 270) (length 2.032) (name "~" (effects (font (size 1.27 1.27)))) (number "1" (effects (font (size 1.27 1.27)))))
				(pin passive line (at 0 -2.54 90) (length 2.032) (name "~" (effects (font (size 1.27 1.27)))) (number "2" (effects (font (size 1.27 1.27)))))
			)
		)
		(symbol "ControlledUsb:Polyfuse"
			(exclude_from_sim no) (in_bom yes) (on_board yes)
			(property "Reference" "F" (at 2.032 0 0) (effects (font (size 1.27 1.27)) (justify left)))
			(property "Value" "Polyfuse" (at 2.032 -2.032 0) (effects (font (size 1.27 1.27)) (justify left)))
			(property "Footprint" "" (at 0 0 0) (effects (font (size 1.27 1.27)) (hide yes)))
			(property "Datasheet" "" (at 0 0 0) (effects (font (size 1.27 1.27)) (hide yes)))
			(property "Description" "" (at 0 0 0) (effects (font (size 1.27 1.27)) (hide yes)))
			(symbol "Polyfuse_0_1"
				(rectangle (start -1.016 2.032) (end 1.016 -2.032) (stroke (width 0.254)) (fill (type none)))
				(polyline (pts (xy -1.524 -1.524) (xy 1.524 1.524)) (stroke (width 0.254)))
			)
			(symbol "Polyfuse_1_1"
				(pin passive line (at 0 3.81 270) (length 1.778) (name "~" (effects (font (size 1.27 1.27)))) (number "1" (effects (font (size 1.27 1.27)))))
				(pin passive line (at 0 -3.81 90) (length 1.778) (name "~" (effects (font (size 1.27 1.27)))) (number "2" (effects (font (size 1.27 1.27)))))
			)
		)
		(symbol "ControlledUsb:Crystal_GND24"
			(exclude_from_sim no) (in_bom yes) (on_board yes)
			(property "Reference" "Y" (at 3.81 2.54 0) (effects (font (size 1.27 1.27)) (justify left)))
			(property "Value" "Crystal_GND24" (at 3.81 0 0) (effects (font (size 1.27 1.27)) (justify left)))
			(property "Footprint" "" (at 0 0 0) (effects (font (size 1.27 1.27)) (hide yes)))
			(property "Datasheet" "" (at 0 0 0) (effects (font (size 1.27 1.27)) (hide yes)))
			(property "Description" "" (at 0 0 0) (effects (font (size 1.27 1.27)) (hide yes)))
			(symbol "Crystal_GND24_0_1"
				(rectangle (start -2.54 3.048) (end 2.54 -3.048) (stroke (width 0.254)) (fill (type background)))
			)
			(symbol "Crystal_GND24_1_1"
				(pin passive line (at -5.08 1.27 0) (length 2.54) (name "1" (effects (font (size 1.27 1.27)))) (number "1" (effects (font (size 1.27 1.27)))))
				(pin power_in line (at 0 -5.08 90) (length 2.032) (name "2" (effects (font (size 1.27 1.27)))) (number "2" (effects (font (size 1.27 1.27)))))
				(pin passive line (at 5.08 1.27 180) (length 2.54) (name "3" (effects (font (size 1.27 1.27)))) (number "3" (effects (font (size 1.27 1.27)))))
				(pin power_in line (at 0 5.08 270) (length 2.032) (name "4" (effects (font (size 1.27 1.27)))) (number "4" (effects (font (size 1.27 1.27)))))
			)
		)
		(symbol "ControlledUsb:USB_A_Plug"
			(pin_names (offset 1.016))
			(exclude_from_sim no) (in_bom yes) (on_board yes)
			(property "Reference" "J" (at 0 7.62 0) (effects (font (size 1.27 1.27))))
			(property "Value" "USB_A_Plug" (at 0 5.08 0) (effects (font (size 1.27 1.27))))
			(property "Footprint" "" (at 0 0 0) (effects (font (size 1.27 1.27)) (hide yes)))
			(property "Datasheet" "" (at 0 0 0) (effects (font (size 1.27 1.27)) (hide yes)))
			(property "Description" "" (at 0 0 0) (effects (font (size 1.27 1.27)) (hide yes)))
			(symbol "USB_A_Plug_0_1"
				(rectangle (start -5.08 3.81) (end 5.08 -8.89) (stroke (width 0.254)) (fill (type background)))
			)
			(symbol "USB_A_Plug_1_1"
				(pin power_out line (at 7.62 2.54 180) (length 2.54) (name "VBUS" (effects (font (size 1.27 1.27)))) (number "1" (effects (font (size 1.27 1.27)))))
				(pin bidirectional line (at 7.62 0 180) (length 2.54) (name "D-" (effects (font (size 1.27 1.27)))) (number "2" (effects (font (size 1.27 1.27)))))
				(pin bidirectional line (at 7.62 -2.54 180) (length 2.54) (name "D+" (effects (font (size 1.27 1.27)))) (number "3" (effects (font (size 1.27 1.27)))))
				(pin power_out line (at 7.62 -5.08 180) (length 2.54) (name "GND" (effects (font (size 1.27 1.27)))) (number "4" (effects (font (size 1.27 1.27)))))
				(pin passive line (at 7.62 -7.62 180) (length 2.54) (name "Shield" (effects (font (size 1.27 1.27)))) (number "5" (effects (font (size 1.27 1.27)))))
			)
		)
		(symbol "ControlledUsb:USB_A_Receptacle"
			(pin_names (offset 1.016))
			(exclude_from_sim no) (in_bom yes) (on_board yes)
			(property "Reference" "J" (at 0 7.62 0) (effects (font (size 1.27 1.27))))
			(property "Value" "USB_A_Receptacle" (at 0 5.08 0) (effects (font (size 1.27 1.27))))
			(property "Footprint" "" (at 0 0 0) (effects (font (size 1.27 1.27)) (hide yes)))
			(property "Datasheet" "" (at 0 0 0) (effects (font (size 1.27 1.27)) (hide yes)))
			(property "Description" "" (at 0 0 0) (effects (font (size 1.27 1.27)) (hide yes)))
			(symbol "USB_A_Receptacle_0_1"
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

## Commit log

2026-10-03 Initial commit: ControlledUsb v2.1 compact hardware and firmware
    [BOM_JLCPCB.csv, ControlledUsb.kicad_pcb, ControlledUsb.kicad_sch]
2026-10-03 Inject electrical netlist for trace routing
    [ControlledUsb.kicad_pcb]
2026-10-03 Auto-route the board using freerouting
    [ControlledUsb.kicad_pcb]
2026-10-03 Generate full graphical schematic with all components and wiring
    [ControlledUsb.kicad_sch]
2026-10-03 Update schematic title layout and add hardware utility scripts
    [ControlledUsb.kicad_sch]
2026-10-04 Complete 100% routing with 0 DRC violations, 0.00mm skew USB differential pairs, and manufacturing deliverables
    [ControlledUsb-B_Cu.gbl, ControlledUsb-B_Mask.gbs, ControlledUsb-B_Paste.gbp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]
2026-10-04 Update BOM_JLCPCB.csv to 100% exact 28-component match with CPL and active schematic
    [BOM_JLCPCB.csv]
2026-10-04 Update CPL column headers to JLCPCB standard (Designator, Mid X, Mid Y, Rotation, Layer)
    [ControlledUsb_CPL.csv]
2026-10-04 Fix J2 USB Female part number to C2344 (902-131A1021D10100 standard USB-A Female RA)
    [BOM_JLCPCB.csv]
2026-10-04 Update Y1,Y2 crystal part number to C9002 (12.000MHz SMD 3225-4P Basic Part)
    [BOM_JLCPCB.csv]
2026-10-04 Update CPL with rotated IC orientations (+90 deg) and J2 centered position
    [ControlledUsb_CPL.csv]
2026-10-05 Fix CPL rotations for U2, U3, U4, U5, U6, U7 to match silkscreen pin 1 marks
    [ControlledUsb_CPL.csv]
2026-10-05 Update BOM_JLCPCB.csv with exact verified in-stock LCSC part numbers
    [BOM_JLCPCB.csv]
2026-10-05 Finalize CPL rotations for U3 (270) and U4 (0)
    [ControlledUsb_CPL.csv]
2026-10-05 Remove D1, SW1, J1 from BOM and CPL; fix U4 rotation to 180 degrees
    [BOM_JLCPCB.csv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]
2026-10-07 Regenerate Gerbers with unified standard decimal Excellon drill file (ControlledUsb.drl) for JLCPCB
    [ControlledUsb-B_Cu.gbl, ControlledUsb-B_Mask.gbs, ControlledUsb-B_Paste.gbp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]
